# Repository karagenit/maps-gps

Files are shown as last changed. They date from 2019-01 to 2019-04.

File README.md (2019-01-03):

# maps-gps
Displaying a Google Maps in a Webpage via GPS Coordinates

Store your API key in a file named `api.key`. Get an API key [here](https://developers.google.com/maps/documentation/javascript/get-api-key).

### URLs

http://serverip:port/map.php displays a google maps.  
http://serverip:port/log.php?lat=xxx&lng=xxx logs a pair of coordinates.

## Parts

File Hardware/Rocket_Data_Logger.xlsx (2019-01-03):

Column1 | Column2 | Column3 | Column4 | Column5 | Column6 | Column7
Part | Value | Device | Package | Description | Mfg. Link | need to buy?
5VOK | GREEN | LED0805_NOOUTLINE | CHIPLED_0805_NOOUTLINE | LED
B1 | 1.8-5V | BATTERY | JSTPH2 | CR1220 SMT - Digikey: 3001K-ND | https://www.arrow.com/en/products/1769/adafruit-industries
C1 | 100n | C-EUC0805 | C0805 | CAPACITOR, European symbol
C2 | 10uF | CAP_CERAMIC0805-NOOUTLINE | 0805-NO | Ceramic Capacitors
C3 | 2.2uF | CAP_CERAMIC0805-NOOUTLINE | 0805-NO | Ceramic Capacitors
C4 | 0.1uF | CAP_CERAMIC0805-NOOUTLINE | 0805-NO | Ceramic Capacitors
C5 | 100uF | C-USC1210 | C1210 | CAPACITOR, American symbol | https://www.arrow.com/en/products/c3225jb0j107m250ac/tdk
C6 | 100uF | C-USC1210 | C1210 | CAPACITOR, American symbol | https://www.arrow.com/en/products/c3225jb0j107m250ac/tdk
C7 | 100n | C-EUC0805 | C0805 | CAPACITOR, European symbol
C14 | 100n | C-EUC0805 | C0805 | CAPACITOR, European symbol
C18 | 100n | C-EUC0805 | C0805 | CAPACITOR, European symbol
D1 |  | DIODE-MINIMELF | MINIMELF | DIODE
D4 |  | DIODE-MINIMELF | MINIMELF | DIODE
DL_328 | ATMEGA328P-AU | ATMEGA328P-AU | TQFP32-08 | MICROCONTROLLER
DL_OK | GREEN | LED0805_NOOUTLINE | CHIPLED_0805_NOOUTLINE | LED
GPS |  | CONN_05 | 1X05 | Multi connection point. Often used as Generic Header-pin footprint for 0.1 inch spaced/style header connections
GPS_328 | ATMEGA328P-AU | ATMEGA328P-AU | TQFP32-08 | MICROCONTROLLER
ICSP_DL | 3x2 M | PINHD-2X3 | 2X03 | PIN HEADER
ICSP_GPS | 3x2 M | PINHD-2X3 | 2X03 | PIN HEADER
IUM |  | CONN_08";1X08" | Multi connection point. Often used as Generic Header-pin footprint for 0.1 inch spaced/style header connections | CONN-08438
J1 |  | CONN_09 | 1X09 | Multi connection point. Often used as Generic Header-pin footprint for 0.1 inch spaced/style header connections
L1 | 6.8uH | INDUCTOR-8X8 | INDUCTOR_8X8MM | Inductors | https://www.arrow.com/en/products/aspiaig-s8050-6r8m-t/abracon
R1 | 1M | R-EU_R0805 | R0805 | RESISTOR, European symbol
R2 | 4.7k | 4.7KOHM1/10W1%(0603) | 0603@1 | RES-07857 | RES-07857
R3 | 1K | RESISTOR0805_NOOUTLINE | 0805-NO | Resistors
R4 | 1K | RESISTOR0805_NOOUTLINE | 0805-NO | Resistors
R5 | 1K | RESISTOR0805_NOOUTLINE | 0805-NO | Resistors
R6 | 1K | RESISTOR0805_NOOUTLINE | 0805-NO | Resistors
R7 | 1.87M | RESISTOR_0805MP | _0805MP | Resistors | https://www.arrow.com/en/products/rmcf0805ft1m87/stackpole-electronics
R8 | 200K | RESISTOR0805_NOOUTLINE | 0805-NO | Resistors
R9 | 4.7k | 4.7KOHM1/10W1%(0603) | 0603@1 | RES-07857 | RES-07857
R11 | 1M | R-EU_R0805 | R0805 | RESISTOR, European symbol
R13 | 4.7k | 4.7KOHM1/10W1%(0603) | 0603@1 | RES-07857 | RES-07857
R14 | 4.7k | 4.7KOHM1/10W1%(0603) | 0603@1 | RES-07857 | RES-07857
R15 | 340K | RESISTOR_0805MP | _0805MP | Resistors
R16 | 1.87M | RESISTOR_0805MP | _0805MP | Resistors | https://www.arrow.com/en/products/rmcf0805ft1m87/stackpole-electronics
SD_COMM |  | M07 | 1X07 | Header 7
SERIAL_DL |  | CONN_03 | 1X03 | Multi connection point. Often used as Generic Header-pin footprint for 0.1 inch spaced/style header connections
SERIAL_GPS |  | CONN_03 | 1X03 | Multi connection point. Often used as Generic Header-pin footprint for 0.1 inch spaced/style header connections
SIM800L(L) |  | CONN_06SILK_FEMALE_PTH | 1X06 | Multi connection point. Often used as Generic Header-pin footprint for 0.1 inch spaced/style header connections | CONN-08437
SIM800L(R) |  | CONN_06SILK_FEMALE_PTH | 1X06 | Multi connection point. Often used as Generic Header-pin footprint for 0.1 inch spaced/style header connections | CONN-08437
SIM_TRANSMIT | GREEN | LED0805_NOOUTLINE | CHIPLED_0805_NOOUTLINE | LED
U$13 | GPS | GPS | GPS
U1 | TPS61030RSAR | VREG_TPS6103X | PVQFN-16 | TPS6103x 4A Boost - 1.8-5.5V Input, Adjustable Output to 5.5V | https://www.arrow.com/en/products/tps61032rsar/texas-instruments
VBATTOK | GREEN | LED0805_NOOUTLINE | CHIPLED_0805_NOOUTLINE | LED
Y1 |  | RESONATORMU | RESONATOR |  | https://www.arrow.com/en/products/cstne16m0vh3l000r0/murata-manufacturing
Y2 |  | RESONATORMU | RESONATOR

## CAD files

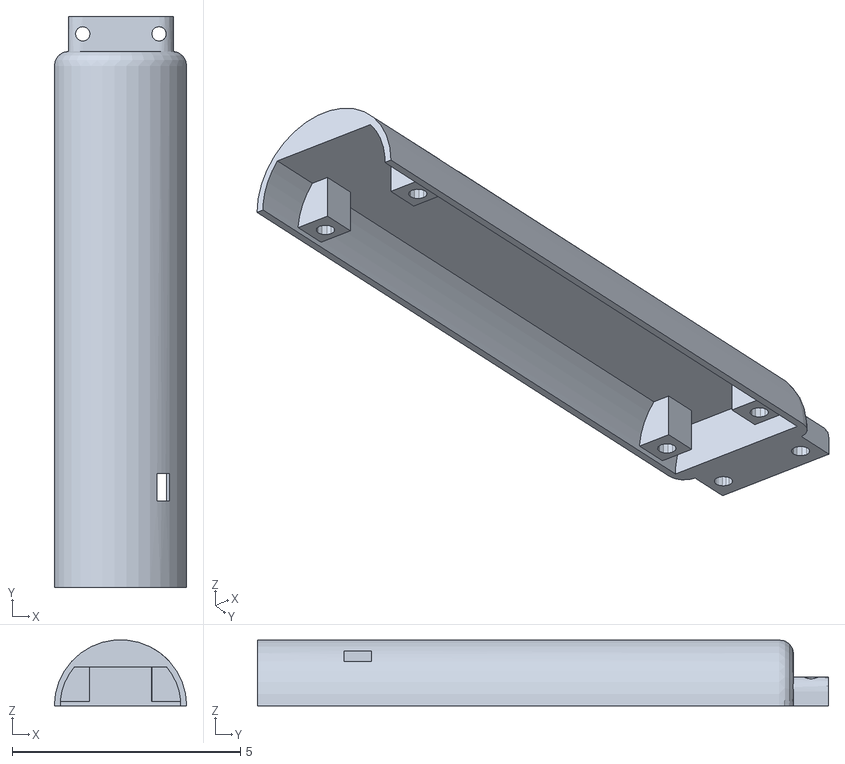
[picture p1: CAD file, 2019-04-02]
Hardware/Bottom tube.stl
2.90 x 12.5 x 1.44

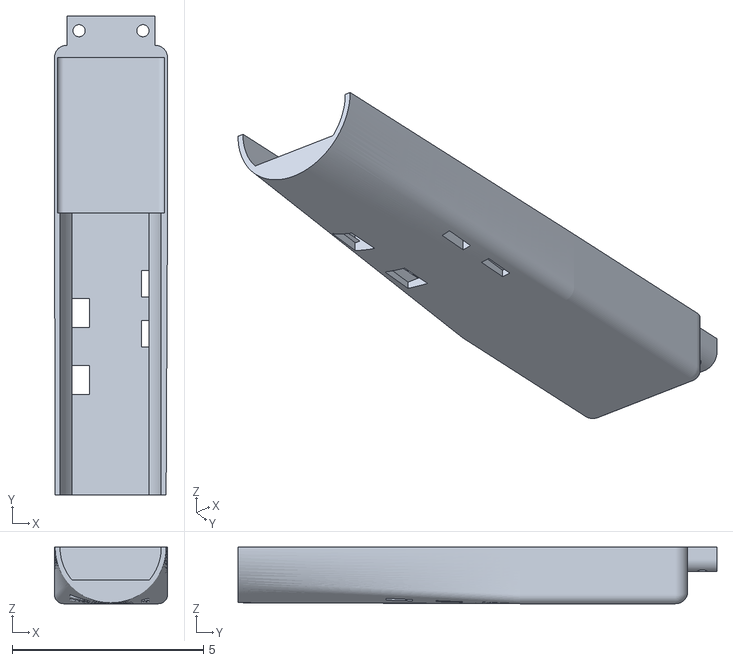
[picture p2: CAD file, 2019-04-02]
Hardware/Tube Top.stl
2.95 x 12.5 x 1.48

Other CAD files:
Hardware/Bottom tube.ipt
Hardware/Rocket Case.iam
Hardware/Rocket_Data_Logger v1.ipt
Hardware/Tube Top.ipt

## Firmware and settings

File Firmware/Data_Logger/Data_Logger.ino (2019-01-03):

#include <Wire.h>
#include <MS5611.h>
#include "I2Cdev.h"
#include "MPU6050.h"
#include <SPI.h>
#include <SD.h>
unsigned long time;
const int chipSelect = 4;
// Arduino Wire library is required if I2Cdev I2CDEV_ARDUINO_WIRE implementation
// is used in I2Cdev.h
#if I2CDEV_IMPLEMENTATION == I2CDEV_ARDUINO_WIRE
#include "Wire.h"
#endif
MPU6050 accelgyro;
//MPU6050 accelgyro(0x69); // <-- use for AD0 high
#define OUTPUT_READABLE_ACCELGYRO
int16_t ax, ay, az;
int16_t gx, gy, gz;

MS5611 ms5611;
double referencePressure;
#define LED_PIN 5
bool blinkState = false;
int intialxraw;

// Altitude (in meters) that the arduino will begin logging data
#define ALT_THRESHOLD (2)

#define LIFTOFF_TIMEOUT (300000)

// Stores our system time (in millis) when we reached "liftoff" (see ALT_THRESHOLD)
unsigned long liftoffTimer = 0;

// Stores arbitrary timestamps for LED blinks
unsigned long ledTimer = 0;
bool ledIsOn = false;

// LED Blink Delay (in milliseconds)
#define LED_TIMEOUT (1000)

void setup()
{
  // join I2C bus (I2Cdev library doesn't do this automatically)
#if I2CDEV_IMPLEMENTATION == I2CDEV_ARDUINO_WIRE
  Wire.begin();
#elif I2CDEV_IMPLEMENTATION == I2CDEV_BUILTIN_FASTWIRE
  Fastwire::setup(400, true);
#endif


  Serial.begin(9600);

  // Initialize MS5611 sensor
  Serial.println("Initialize MS5611 Sensor");

  while (!ms5611.begin())
  {
    Serial.println("Could not find a valid MS5611 sensor, check wiring!");
    delay(500);
  }

  // Get reference pressure for relative altitude
  referencePressure = ms5611.readPressure();

  // Check settings
  checkSettings();

  // initialize device
  Serial.println("Initializing I2C devices...");
  accelgyro.initialize();

  // verify connection
  Serial.println("Testing device connections...");
  Serial.println(accelgyro.testConnection() ? "MPU6050 connection successful" : "MPU6050 connection failed");
  pinMode(LED_PIN, OUTPUT);
  accelgyro.getAcceleration(&ax, &ay, &az);
  intialxraw = ax;

  Serial.print("Initializing SD card...");
  if (!SD.begin(chipSelect)) {// see if the card is present and can be initialized:
    Serial.println("Card failed, or not present");
    // don't do anything more:
    return;
  }
  Serial.println("card initialized.");

}

void checkSettings()
{
  // Serial.print("Oversampling: ");
  // Serial.println(ms5611.getOversampling());
}

void loop()
{
  // read raw accel measurements from device
  accelgyro.getAcceleration(&ax, &ay, &az);

  // Read raw pressure and temp values
  uint32_t rawTemp = ms5611.readRawTemperature();
  uint32_t rawPressure = ms5611.readRawPressure();

  // Read true temperature & Pressure
  double realTemperature = ms5611.readTemperature();
  long realPressure = ms5611.readPressure();

  // Calculate altitude
  float absoluteAltitude = ms5611.getAltitude(realPressure);
  float relativeAltitude = ms5611.getAltitude(realPressure, referencePressure);


  //change variables to strings
  String comma = String (',');
  String absalt = String(relativeAltitude);
  String temp = String ( ms5611.readTemperature()); //real temp in degrees, may over read initially, will take time for sensor to stabilize.
  String realpressure = String (ms5611.readPressure()); // pressure in pascals
  String accelXraw = String (ax - intialxraw); // raw accel in X. Divide by 2048 to get a "G" reading.
  String timer = String (millis()); //puts a millis time stamp on each string.
  //make a big string containing above strings
  String Baro_data = String  (absalt + comma + temp + comma + realpressure + comma + accelXraw + comma + timer) ;

  Serial.println (Baro_data);

  // if we haven't started the liftoff timeout, but we are above the altitude threshold, save the current timestamp
  if ((liftoffTimer == 0) && (relativeAltitude > ALT_THRESHOLD)) {
    liftoffTimer = millis();
  }

  if ((relativeAltitude > ALT_THRESHOLD) && ((millis() - liftoffTimer) < LIFTOFF_TIMEOUT)) {
  File dataFile = SD.open("datalog.txt", FILE_WRITE);
    // if the file is available, write to it:
    if (dataFile) {
      dataFile.println(Baro_data);//put Baro_data on the SD card
      dataFile.close();
      Serial.println("wrote data to card");
      if (millis() > 10000) //change this number to change alarm delay (1s = 1000ms)
      {
        tone (8, 1000); // change the second number to alter the tone of the peizo alarm
      }
      else
      {
        noTone(8);
      }
    } // if (dataFile)
  } // ALT_THRESHOLD

  // Blink LED
  if ((millis() - ledTimer) > LED_TIMEOUT) {
    ledTimer = millis(); //reset timer
    if (ledIsOn) {
      digitalWrite(LED_PIN, LOW);
      ledIsOn = false;
    } else {
      digitalWrite(LED_PIN, HIGH);
      ledIsOn = true;
    }
  }
}

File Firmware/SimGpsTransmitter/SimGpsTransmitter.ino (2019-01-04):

/*
  SIM GPS Transmitter

  Simple project which logs data from GPS module (NEO 6M) into a web service using data HTTP GET requests through SIM800L module.
  Location is sent for each interval given as configuration variable 'frequency'.

  Connecting modules:
  Pin3 -> GPS-module-RX
  Pin4 -> GPS-module-TX
  Pin5 -> SIM-module-TX
  Pin6 -> SIM-module-RX

  Dependency(TinyGPS++ library): http://arduiniana.org/libraries/tinygpsplus/

  created   Jul 2017
  by CheapskateProjects
  edtied by Derek Fronek 2018

  ---------------------------
  The MIT License (MIT)

  Copyright (c) 2017 CheapskateProjects

  Permission is hereby granted, free of charge, to any person obtaining a copy of this software and associated documentation files (the "Software"), to deal in the Software without restriction, including without limitation the rights to use, copy, modify, merge, publish, distribute, sublicense, and/or sell copies of the Software, and to permit persons to whom the Software is furnished to do so, subject to the following conditions:

  The above copyright notice and this permission notice shall be included in all copies or substantial portions of the Software.

  THE SOFTWARE IS PROVIDED "AS IS", WITHOUT WARRANTY OF ANY KIND, EXPRESS OR IMPLIED, INCLUDING BUT NOT LIMITED TO THE WARRANTIES OF MERCHANTABILITY, FITNESS FOR A PARTICULAR PURPOSE AND NONINFRINGEMENT. IN NO EVENT SHALL THE AUTHORS OR COPYRIGHT HOLDERS BE LIABLE FOR ANY CLAIM, DAMAGES OR OTHER LIABILITY, WHETHER IN AN ACTION OF CONTRACT, TORT OR OTHERWISE, ARISING FROM, OUT OF OR IN CONNECTION WITH THE SOFTWARE OR THE USE OR OTHER DEALINGS IN THE SOFTWARE.
*/

#include <SoftwareSerial.h>
#include <TinyGPS++.h>

// Config (Use APN corresponding to your service providers configs)
static String apn = "yourAPN";
static String loggingPassword = "";
static String serverIP = "your ip";

// Pins where GPS and SIM modules are connected
static const int SimRXPin = A3, SimTXPin = A2;
static const int GPSRXPin = 3, GPSTXPin = 4;
static const int ErrorPin = 6, SimConnectionPin = 10;

// Used baud rates (define based on used modules)
static const uint32_t SimBaudrate = 9600;
static const uint32_t GPSBaud = 9600;
static const uint32_t SerialBaudrate = 9600;

// How frequently we want to send the location (milliseconds)
static const unsigned long frequency = 15000;

// Maximum time to wait SIM module for response
static long maxResponseTime = 30000;

String responseString;
TinyGPSPlus gps;
unsigned long previous = 0;
unsigned long beltTime;
SoftwareSerial sim_ss(SimRXPin, SimTXPin);
SoftwareSerial gps_ss(GPSRXPin, GPSTXPin);

void setup()
{
  // Initialize status pins
  pinMode(ErrorPin, OUTPUT);
  pinMode(SimConnectionPin, OUTPUT);
  digitalWrite(ErrorPin, LOW);
  digitalWrite(SimConnectionPin, LOW);

  /*
     Start serial communications. We can only listen to one ss at a time so changing that
     between sim and gps as needed
  */
  Serial.begin(SerialBaudrate);
  sim_ss.begin(SimBaudrate);
  gps_ss.begin(GPSBaud);
  sim_ss.listen();

  Serial.println("Waiting for init");
  // Wait few seconds so that module is able to take AT commands
  delay(15000);
  Serial.println("Init... waiting until module has connected to network");

  // Start AT communication. This sets auto baud and enables module to send data
  sim_ss.println("AT");
  // Wait until module is connected and ready
  waitUntilResponse("OK");
  blinkLed(SimConnectionPin);


  // Full mode
  sim_ss.println("AT+CFUN=1");
  waitUntilResponse("OK");
  blinkLed(SimConnectionPin);

  // Set credentials (TODO username and password are not configurable from variables). This may work without CSTT and CIICR but sometimes it caused error without them even though APN is given by SAPBR
  sim_ss.write("AT+CSTT=\"");
  sim_ss.print(apn);
  sim_ss.write("\",\"\",\"\"\r\n");
  waitUntilResponse("OK");
  blinkLed(SimConnectionPin);


  // Connect and get IP
  sim_ss.println("AT+CIICR");
  waitUntilResponse("OK");
  blinkLed(SimConnectionPin);

  // Some more credentials
  sim_ss.write("AT+SAPBR=3,1,\"APN\",\"");
  sim_ss.print(apn);
  sim_ss.write("\"\r\n");
  waitUntilResponse("OK");
  blinkLed(SimConnectionPin);

  sim_ss.println("AT+SAPBR=3,1,\"USER\",\"\"");
  waitUntilResponse("OK");
  blinkLed(SimConnectionPin);

  sim_ss.println("AT+SAPBR=3,1,\"PWD\",\"\"");
  waitUntilResponse("OK");
  blinkLed(SimConnectionPin);

  sim_ss.println("AT+SAPBR=1,1");
  waitUntilResponse("OK");
  blinkLed(SimConnectionPin);

  sim_ss.println("AT+HTTPINIT");
  waitUntilResponse("OK");
  digitalWrite(SimConnectionPin, HIGH);

  gps_ss.listen();
  previous = millis();
  Serial.println("starting loop!");
}

void blinkLed(int led)
{
  digitalWrite(led, HIGH);
  delay(20);
  digitalWrite(led, LOW);
}

/*
    Read from SIM serial until we get known response. TODO error handling!
 * */
void waitUntilResponse(String response)
{
  beltTime = millis();
  responseString = "";
  String totalResponse = "";
  while (responseString.indexOf(response) < 0 && millis() - beltTime < maxResponseTime)
  {
    readResponse();
    totalResponse = totalResponse + responseString;
    Serial.println(responseString);
  }

  if (totalResponse.length() <= 0)
  {
    Serial.println("No response from the module. Check wiring, SIM-card and power!");
    digitalWrite(ErrorPin, HIGH);
    delay(30000);
    exit(0); // No way to recover
  }
  else if (responseString.indexOf(response) < 0)
  {
    Serial.println("Unexpected response from the module");
    Serial.println(totalResponse);
    digitalWrite(ErrorPin, HIGH);
    delay(30000);
    exit(0); // No way to recover
  }
}

/*
   Read from serial until we get response line ending with line separator
 * */
void readResponse()
{
  responseString = "";
  while (responseString.length() <= 0 || !responseString.endsWith("\n"))
  {
    tryToRead();

    if (millis() - beltTime > maxResponseTime)
    {
      return;
    }
  }
}

/*
   If we have anything available on the serial, append it to response string
 * */
void tryToRead()
{
  while (sim_ss.available())
  {
    char c = sim_ss.read();  //gets one byte from serial buffer
    responseString += c; //makes the string readString
  }
}

void loop()
{
  // If we have data, decode and log the data
  while (gps_ss.available() > 0)
    if (gps.encode(gps_ss.read()))
      logInfo();

  // Test that we have had something from GPS module within first 10 seconds
  if (millis() - previous > 10000 && gps.charsProcessed() < 10)
  {
    Serial.println("GPS wiring error!");
    while (true);
  }
}
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
